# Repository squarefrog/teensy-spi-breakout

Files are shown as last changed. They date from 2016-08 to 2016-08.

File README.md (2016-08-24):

# Teensy 3.2 SPI Breakout Board



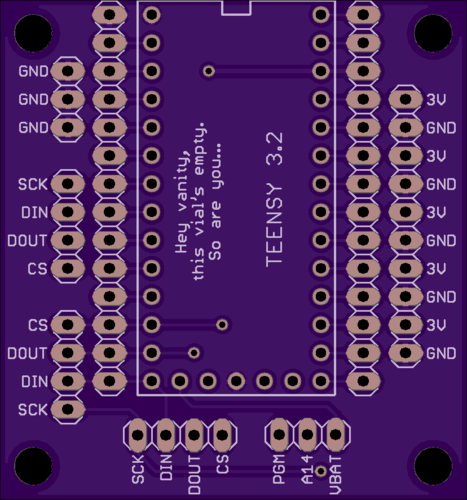
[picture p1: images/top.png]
Board top

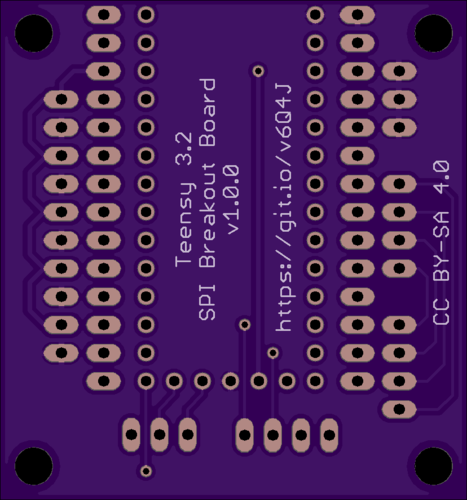
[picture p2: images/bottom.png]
Board bottom


A 45x42mm breakout board for the [Teensy 3.2](https://www.pjrc.com/teensy/teensy31.html). It features a tonne of `3V` and `GND` pins, as well as 3 header pins for SPI connections. There are smaller more concise breakouts, but I needed something that placed the Teensy's USB port at the top, with 4 decent sized mount points.

As used in my [MIDI Encoder Box](https://github.com/squarefrog/teensy-midi-encoder-box) project.

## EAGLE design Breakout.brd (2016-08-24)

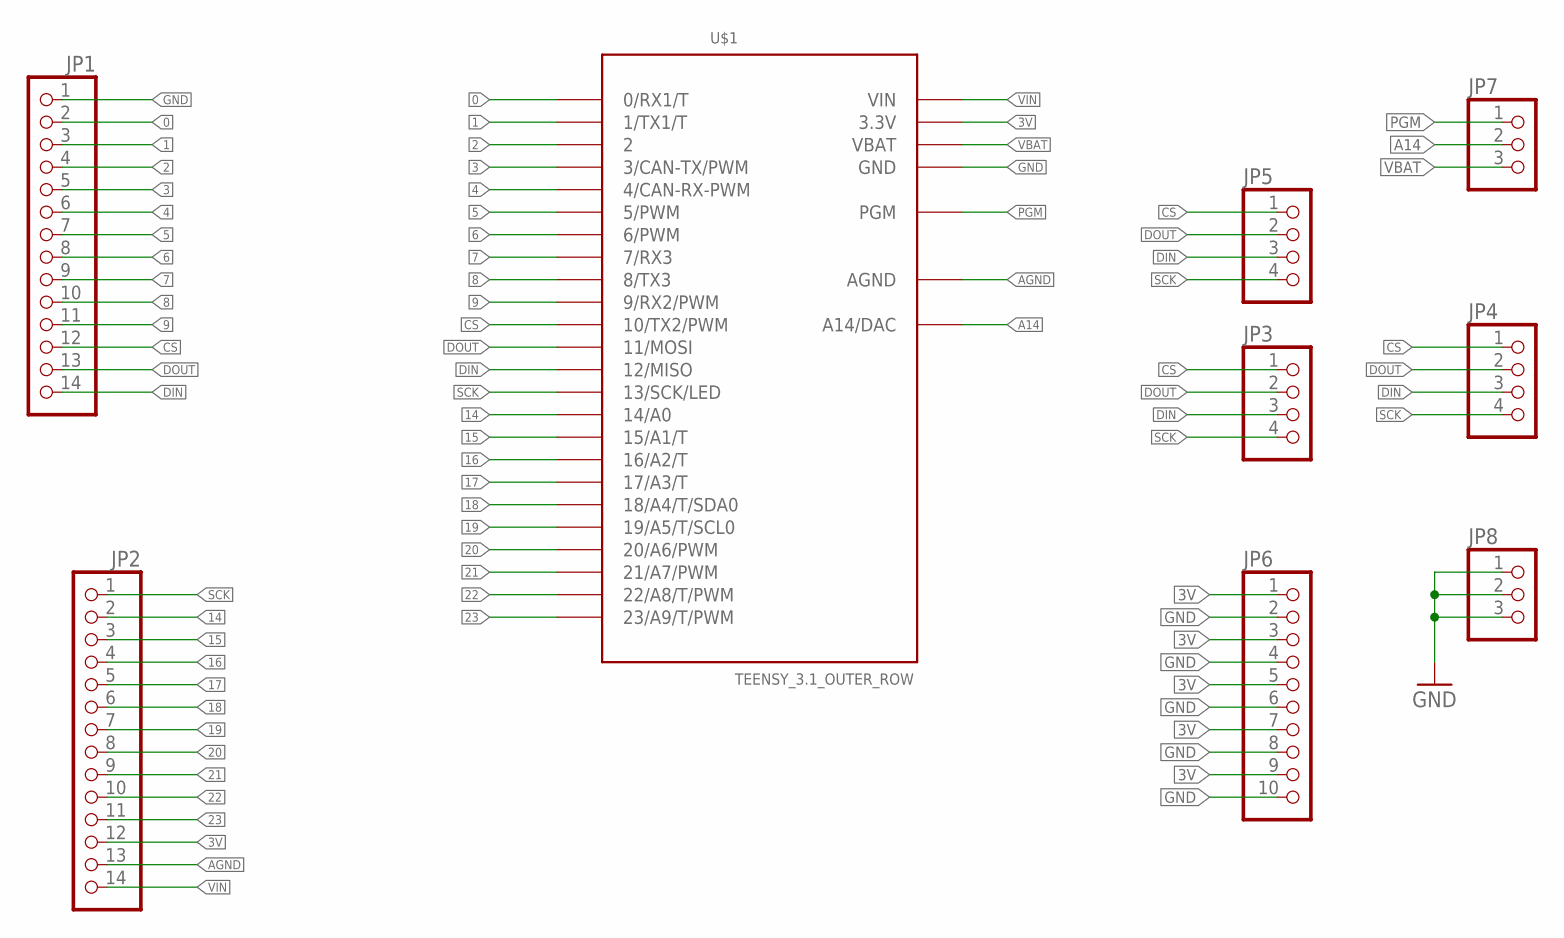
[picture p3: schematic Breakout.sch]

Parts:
JP1, JP2: PINHD-1X14; 1X14
JP3, JP4, JP5: PINHD-1X4; 1X04
JP6: PINHD-1X10; 1X10
JP7, JP8: PINHD-1X3; 1X03
U$1: TEENSY_3.1_OUTER_ROW; TEENSY3-OUTER_ROW

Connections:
0: JP1.2, U$1.0 (0/RX1/T)
1: JP1.3, U$1.1 (1/TX1/T)
2: JP1.4, U$1.2
3: JP1.5, U$1.3 (3/CAN-TX/PWM)
3V: JP2.12, JP6.1, JP6.3, JP6.5, JP6.7, JP6.9, U$1.3.3V, U$1.3.3V1 (3.3V)
4: JP1.6, U$1.4 (4/CAN-RX-PWM)
5: JP1.7, U$1.5 (5/PWM)
6: JP1.8, U$1.6 (6/PWM)
7: JP1.9, U$1.7 (7/RX3)
8: JP1.10, U$1.8 (8/TX3)
9: JP1.11, U$1.9 (9/RX2/PWM)
14: JP2.2, U$1.14/A0
15: JP2.3, U$1.15/A1 (15/A1/T)
16: JP2.4, U$1.16/A2 (16/A2/T)
17: JP2.5, U$1.17/A3 (17/A3/T)
18: JP2.6, U$1.18/A4 (18/A4/T/SDA0)
19: JP2.7, U$1.19/A5 (19/A5/T/SCL0)
20: JP2.8, U$1.20/A6 (20/A6/PWM)
21: JP2.9, U$1.21/A7 (21/A7/PWM)
22: JP2.10, U$1.22/A8 (22/A8/T/PWM)
23: JP2.11, U$1.23/A9 (23/A9/T/PWM)
A14: JP7.2, U$1.RESET/DAC (A14/DAC)
AGND: JP2.13, U$1.AGND
CS: JP1.12, JP3.1, JP4.1, JP5.1, U$1.10 (10/TX2/PWM)
DIN: JP1.14, JP3.3, JP4.3, JP5.3, U$1.12 (12/MISO)
DOUT: JP1.13, JP3.2, JP4.2, JP5.2, U$1.11 (11/MOSI)
GND: JP1.1, JP6.2, JP6.4, JP6.6, JP6.8, JP6.10, JP8.1, JP8.2, JP8.3, U$1.GND, U$1.GND1 (GND)
PGM: JP7.1, U$1.PGM
SCK: JP2.1, JP3.4, JP4.4, JP5.4, U$1.13 (13/SCK/LED)
VBAT: JP7.3, U$1.VBAT
VIN: JP2.14, U$1.VIN

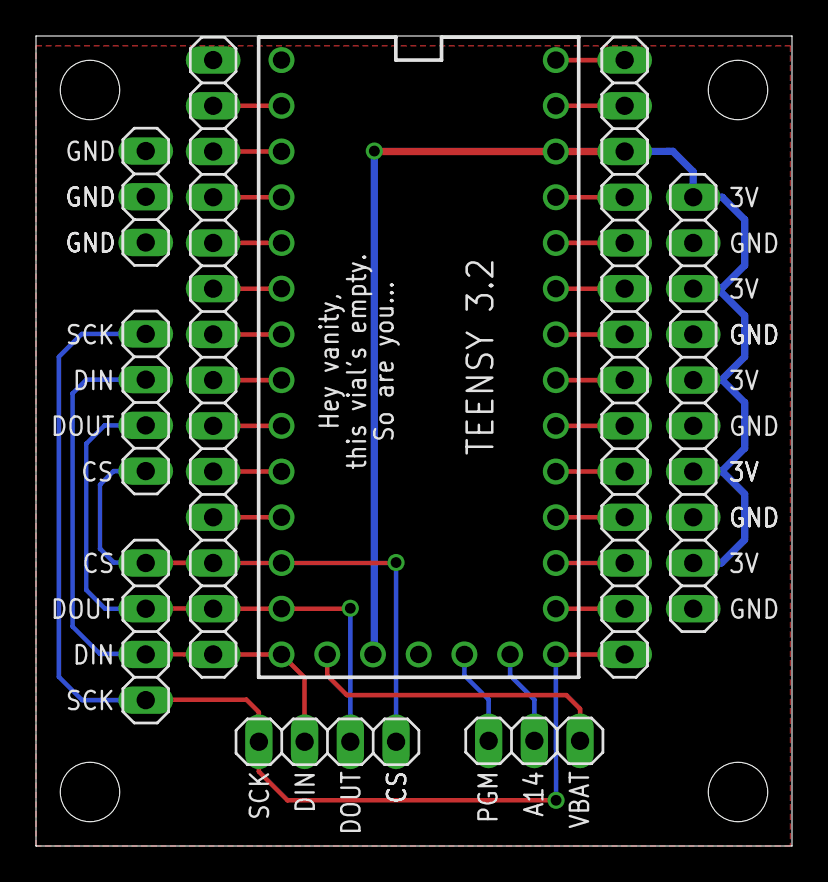
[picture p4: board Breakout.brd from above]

Board: 2 copper layers, 42.0 x 45.0 mm, 13 parts (0 on the bottom side), 31 nets.

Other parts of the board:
U$2, U$3, U$4, U$5: STAND-OFF

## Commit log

2016-08-24 Nudge layout to fit more squarely on mil grid
    [Breakout.brd, Breakout.sch]
2016-08-24 Add ALL the GNDs...
    [Breakout.brd, Breakout.sch]
2016-08-24 Fixup ERC
    [Breakout.brd, Breakout.sch]

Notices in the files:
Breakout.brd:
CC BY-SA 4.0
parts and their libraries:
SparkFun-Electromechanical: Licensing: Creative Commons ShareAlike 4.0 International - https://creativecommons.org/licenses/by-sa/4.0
